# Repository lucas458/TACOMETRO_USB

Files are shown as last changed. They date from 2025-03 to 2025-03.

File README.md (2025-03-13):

# TACOMETRO USB
## Tacômetro USB para jogos usando PIC12F1822.

#### Placa
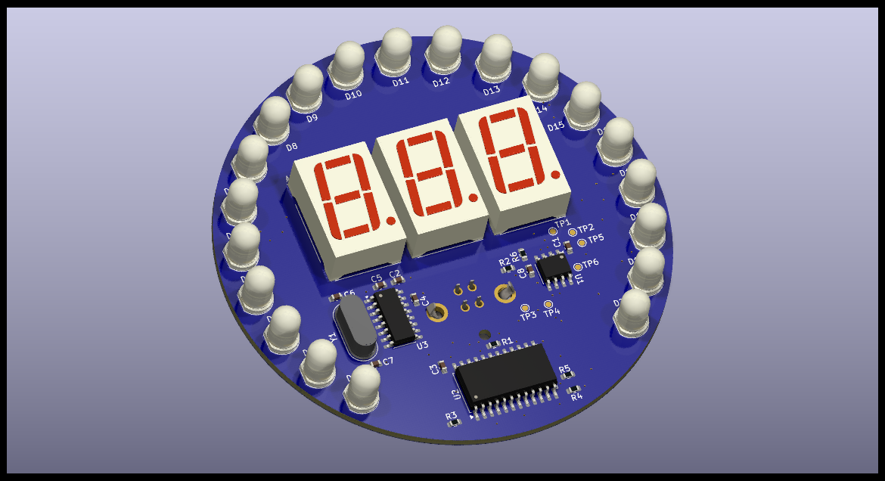
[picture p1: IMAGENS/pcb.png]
Placa da Placa Frente da placa


### Os dados a serem enviados são compostos por 6 bytes e serão transmitidos pela porta serial.
| Buffer Index | Valor (decimal) | Descrição |
| --- | --- | --- |
| 0 | 0 a 255 | Digito 0 |
| 1 | 0 a 255 | Digito 1 |
| 2 | 0 a 255 | Digito 2 |
| 3 | 0 a 20 | Quantidade de LEDS ligados |
| 4 | 0 a 15 | Brilho |
| 5 | '\r' ou '\n' | **Caractere obrigatório** |

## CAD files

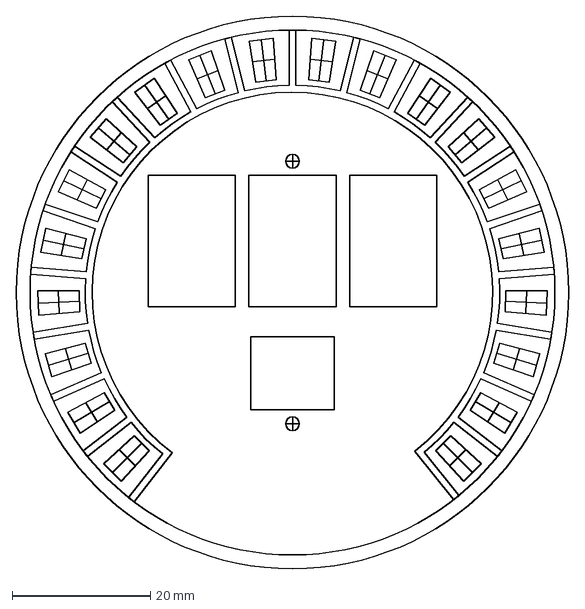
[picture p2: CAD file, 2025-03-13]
PCB/ledGaugePCB.dxf
80.0 x 80.0 mm

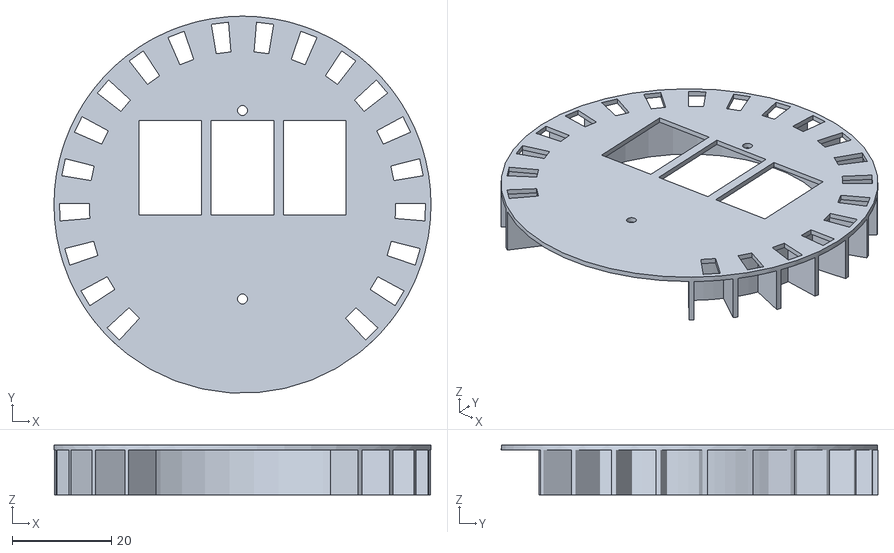
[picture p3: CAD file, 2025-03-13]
ESTRUTURA/frente.stl
76.0 x 75.9 x 10.0

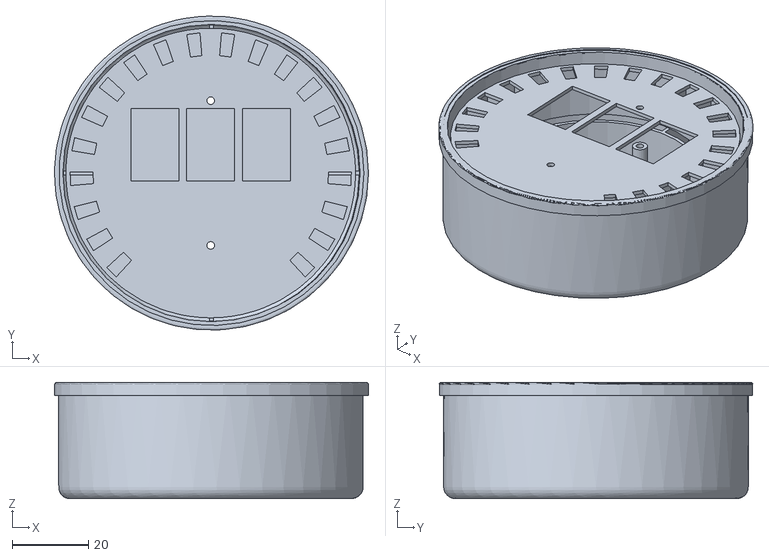
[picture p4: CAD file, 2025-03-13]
ESTRUTURA/estrutura.stl
82.4 x 82.3 x 30.5

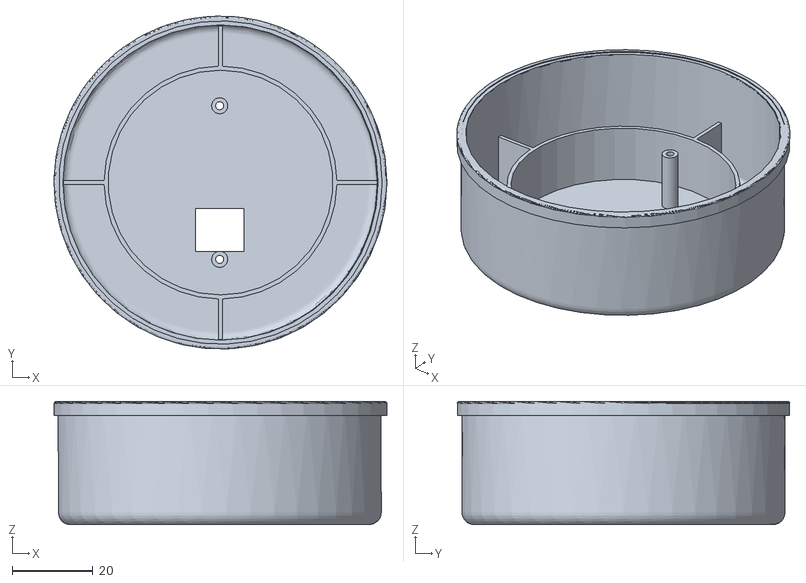
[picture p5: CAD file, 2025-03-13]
ESTRUTURA/corpo.stl
82.4 x 82.3 x 30.5

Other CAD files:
ESTRUTURA/estruturaProjeto.dwg
ESTRUTURA/estrutura.dwg

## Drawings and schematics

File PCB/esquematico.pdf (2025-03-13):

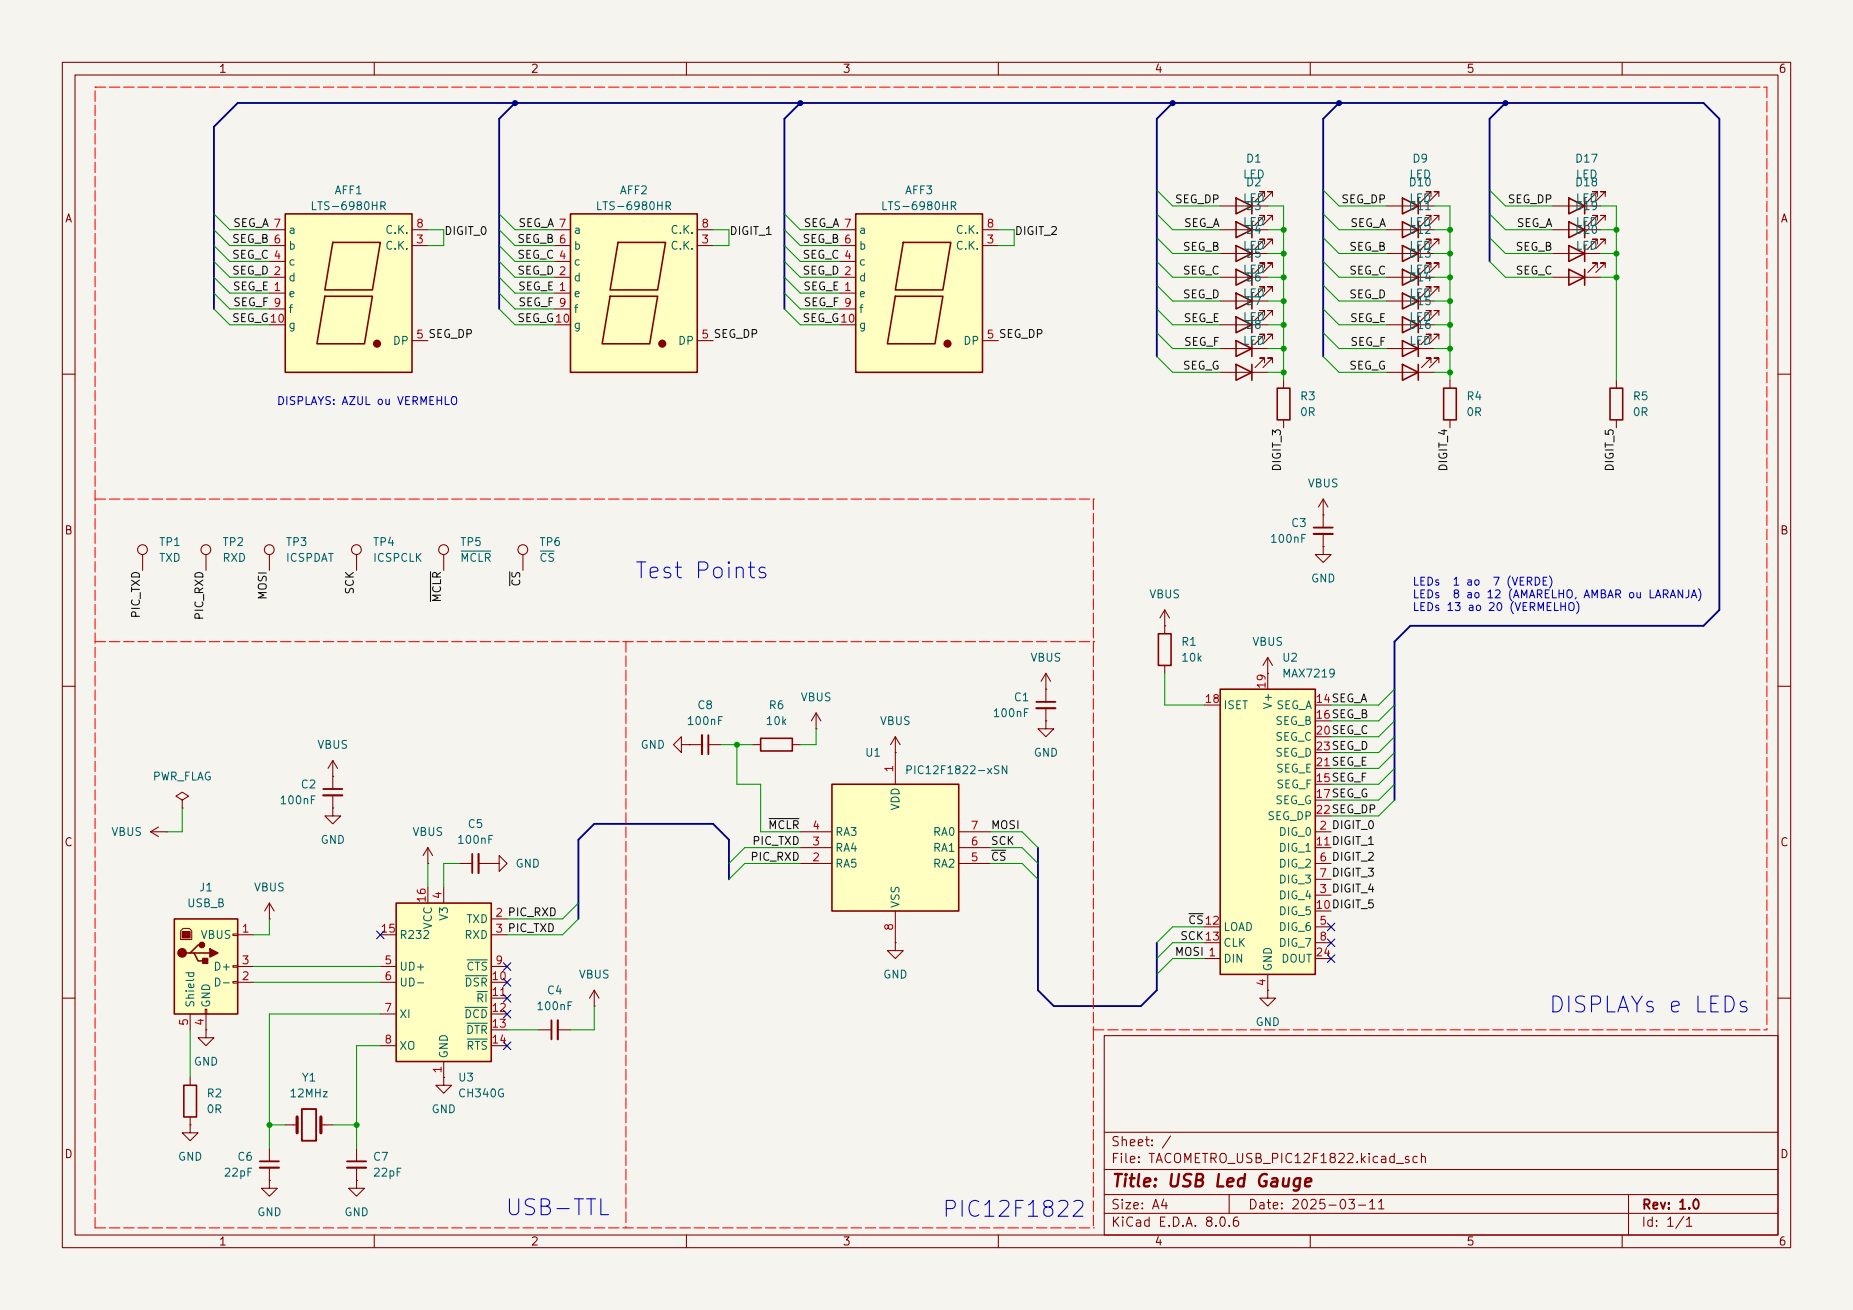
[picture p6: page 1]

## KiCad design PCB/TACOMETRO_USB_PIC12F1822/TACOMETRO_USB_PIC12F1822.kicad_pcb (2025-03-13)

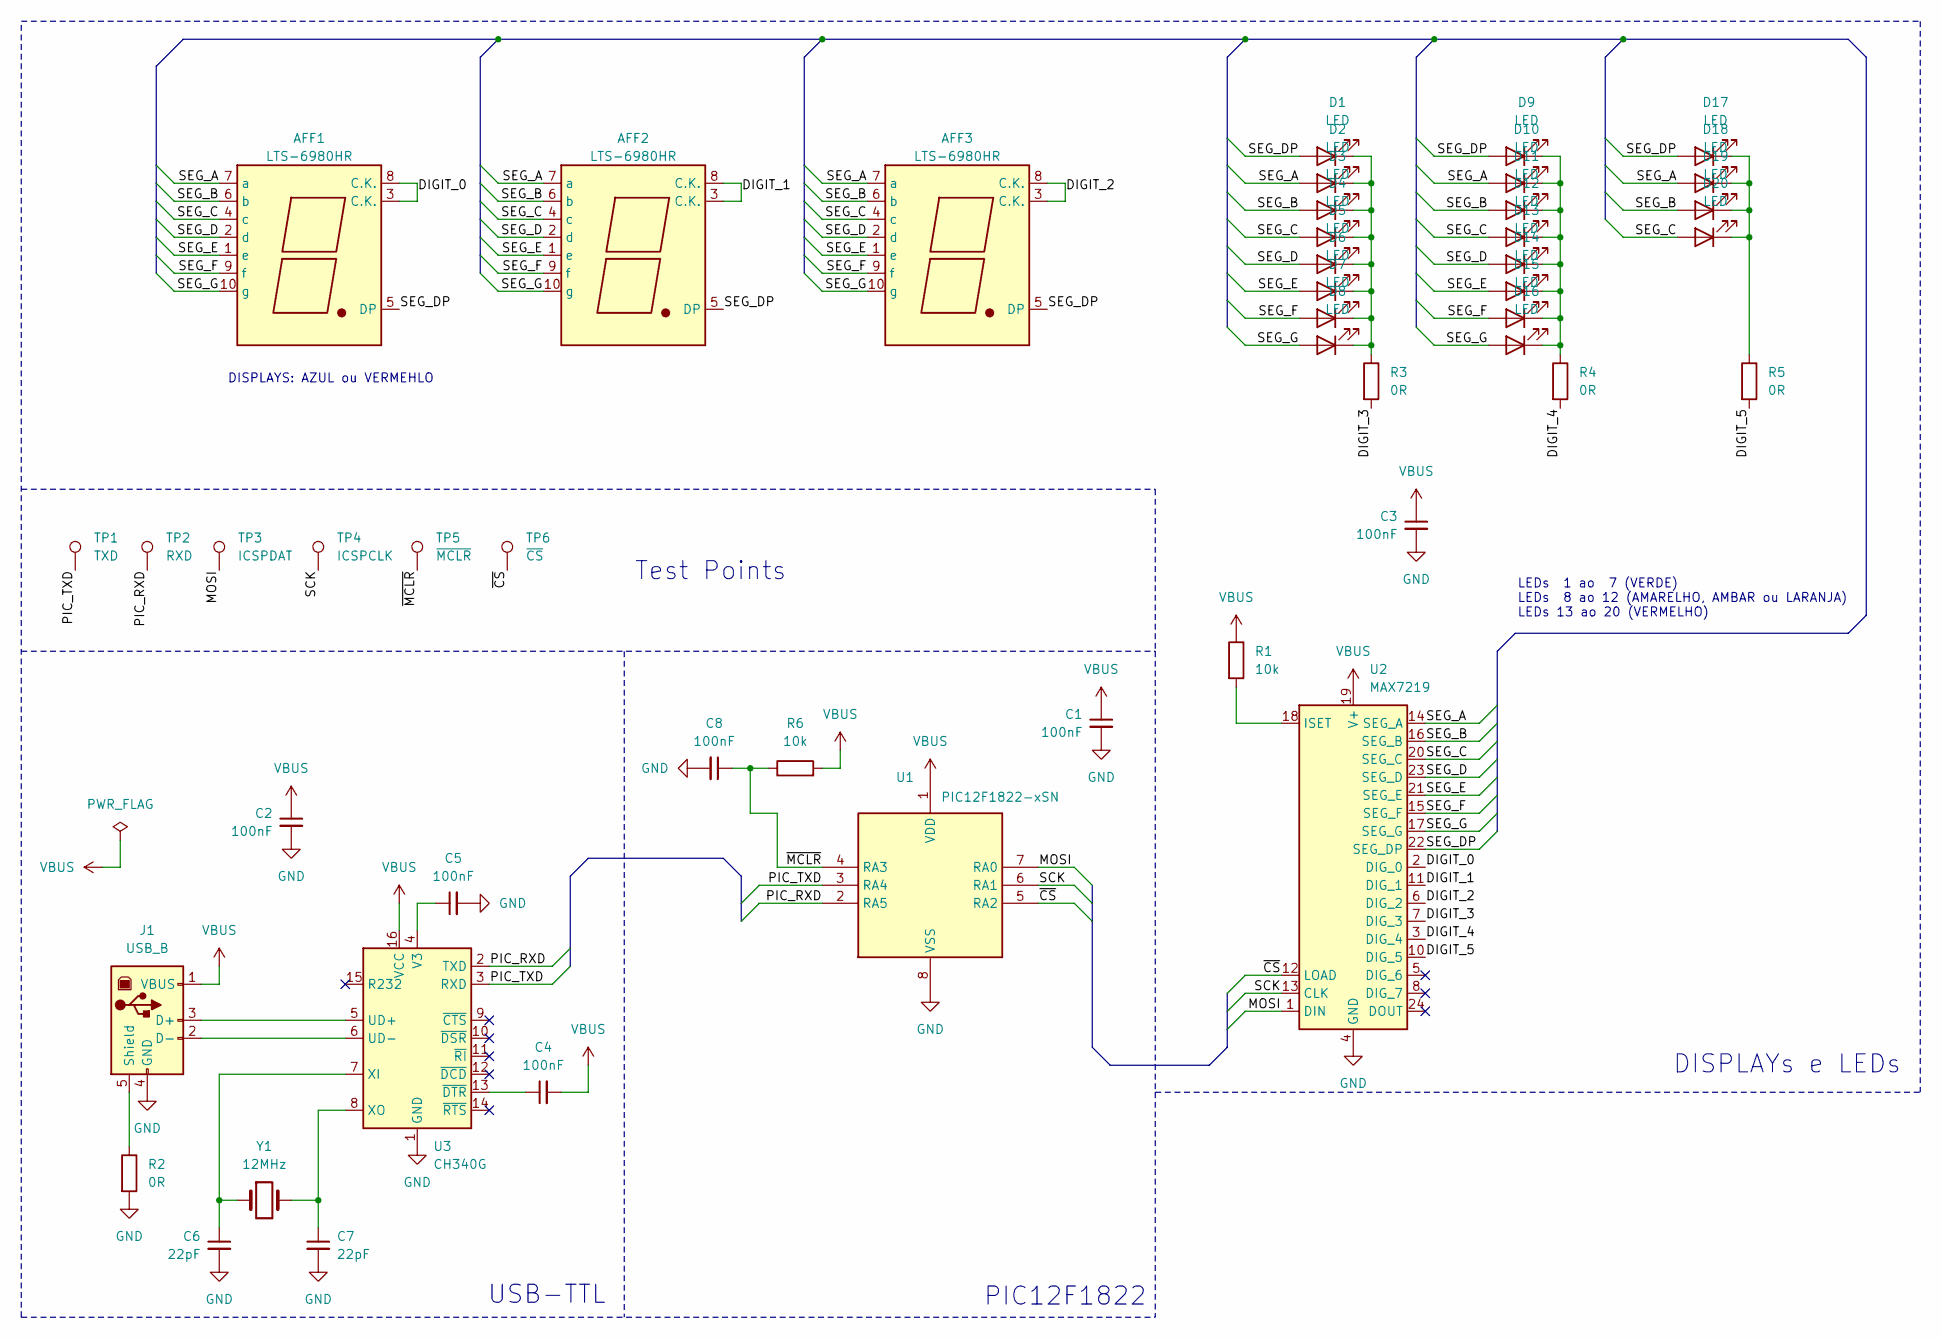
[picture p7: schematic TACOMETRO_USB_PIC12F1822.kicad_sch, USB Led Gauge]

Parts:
AFF1, AFF2, AFF3: LTS-6980HR; 7SegmentLED_LTS6760_LTS6780
C1, C2, C3, C4, C5, C8: 100nF; C_0603_1608Metric
C6, C7: 22pF; C_0603_1608Metric
D1, D2, D3, D4, D5, D6, D7, D8, D9, D10, D11, D12, D13, D14, D15, D16, D17, D18, D19, D20: LED; LED_D5.0mm_Clear
J1: USB_B; 5787834-1
R1, R6: 10k; R_0603_1608Metric
R2, R3, R4, R5: 0R; R_0603_1608Metric
TP1: TXD; TestPoint_Pad_D1.0mm
TP2: RXD; TestPoint_Pad_D1.0mm
TP3: ICSPDAT; TestPoint_Pad_D1.0mm
TP4: ICSPCLK; TestPoint_Pad_D1.0mm
TP5: ~{MCLR}; TestPoint_Pad_D1.0mm
TP6: ~{CS}; TestPoint_Pad_D1.0mm
U1: PIC12F1822-xSN; SOIC-8_3.9x4.9mm_P1.27mm
U2: MAX7219; SOIC-24W_7.5x15.4mm_P1.27mm
U3: CH340G; SOIC-16_3.9x9.9mm_P1.27mm
Y1: 12MHz; Crystal_HC49-U_Vertical

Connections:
/DIGIT_0: AFF1.3 (C.K.), AFF1.8 (C.K.), U2.2 (DIG_0)
/DIGIT_1: AFF2.3 (C.K.), AFF2.8 (C.K.), U2.11 (DIG_1)
/DIGIT_2: AFF3.3 (C.K.), AFF3.8 (C.K.), U2.6 (DIG_2)
/DIGIT_3: R3.2, U2.7 (DIG_3)
/DIGIT_4: R4.2, U2.3 (DIG_4)
/DIGIT_5: R5.2, U2.10 (DIG_5)
/MOSI: TP3.1, U1.7 (RA0), U2.1 (DIN)
/PIC_RXD: TP2.1, U1.2 (RA5), U3.2 (TXD)
/PIC_TXD: TP1.1, U1.3 (RA4), U3.3 (RXD)
/SCK: TP4.1, U1.6 (RA1), U2.13 (CLK)
/SEG_A: AFF1.7 (a), AFF2.7 (a), AFF3.7 (a), D2.2 (A), D10.2 (A), D18.2 (A), U2.14 (SEG_A)
/SEG_B: AFF1.6 (b), AFF2.6 (b), AFF3.6 (b), D3.2 (A), D11.2 (A), D19.2 (A), U2.16 (SEG_B)
/SEG_C: AFF1.4 (c), AFF2.4 (c), AFF3.4 (c), D4.2 (A), D12.2 (A), D20.2 (A), U2.20 (SEG_C)
/SEG_D: AFF1.2 (d), AFF2.2 (d), AFF3.2 (d), D5.2 (A), D13.2 (A), U2.23 (SEG_D)
/SEG_DP: AFF1.5 (DP), AFF2.5 (DP), AFF3.5 (DP), D1.2 (A), D9.2 (A), D17.2 (A), U2.22 (SEG_DP)
/SEG_E: AFF1.1 (e), AFF2.1 (e), AFF3.1 (e), D6.2 (A), D14.2 (A), U2.21 (SEG_E)
/SEG_F: AFF1.9 (f), AFF2.9 (f), AFF3.9 (f), D7.2 (A), D15.2 (A), U2.15 (SEG_F)
/SEG_G: AFF1.10 (g), AFF2.10 (g), AFF3.10 (g), D8.2 (A), D16.2 (A), U2.17 (SEG_G)
/~CS: TP6.1, U1.5 (RA2), U2.12 (LOAD)
/~MCLR: C8.1, R6.1, TP5.1, U1.4 (RA3)
GND: C1.2, C2.2, C3.2, C5.2, C6.2, C7.2, C8.2, J1.4 (GND), R2.2, U1.8 (VSS), U2.4 (GND), U2.9 (GND), U3.1 (GND)
unnamed: D1.1 (K), D2.1 (K), D3.1 (K), D4.1 (K), D5.1 (K), D6.1 (K), D7.1 (K), D8.1 (K), R3.1
unnamed: D9.1 (K), D10.1 (K), D11.1 (K), D12.1 (K), D13.1 (K), D14.1 (K), D15.1 (K), D16.1 (K), R4.1
unnamed: D17.1 (K), D18.1 (K), D19.1 (K), D20.1 (K), R5.1
unnamed: J1.3 (D+), U3.5 (UD+)
unnamed: J1.2 (D-), U3.6 (UD-)
unnamed: J1.5 (Shield), R2.1
unnamed: R1.2, U2.18 (ISET)
unnamed: C5.1, U3.4 (V3)
unnamed: C6.1, U3.7 (XI), Y1.1
unnamed: C7.1, U3.8 (XO), Y1.2
unnamed: C4.1, U3.13 (~DTR)
VBUS: C1.1, C2.1, C3.1, C4.2, J1.1 (VBUS), R1.1, R6.2, U1.1 (VDD), U2.19 (V+), U3.16 (VCC)

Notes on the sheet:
Test Points
USB-TTL
LEDs 1 ao 7 (VERDE) LEDs 8 ao 12 (AMARELHO, AMBAR ou LARANJA) LEDs 13 ao 20 (VERMELHO)
DISPLAYS: AZUL ou VERMEHLO
PIC12F1822
DISPLAYs e LEDs

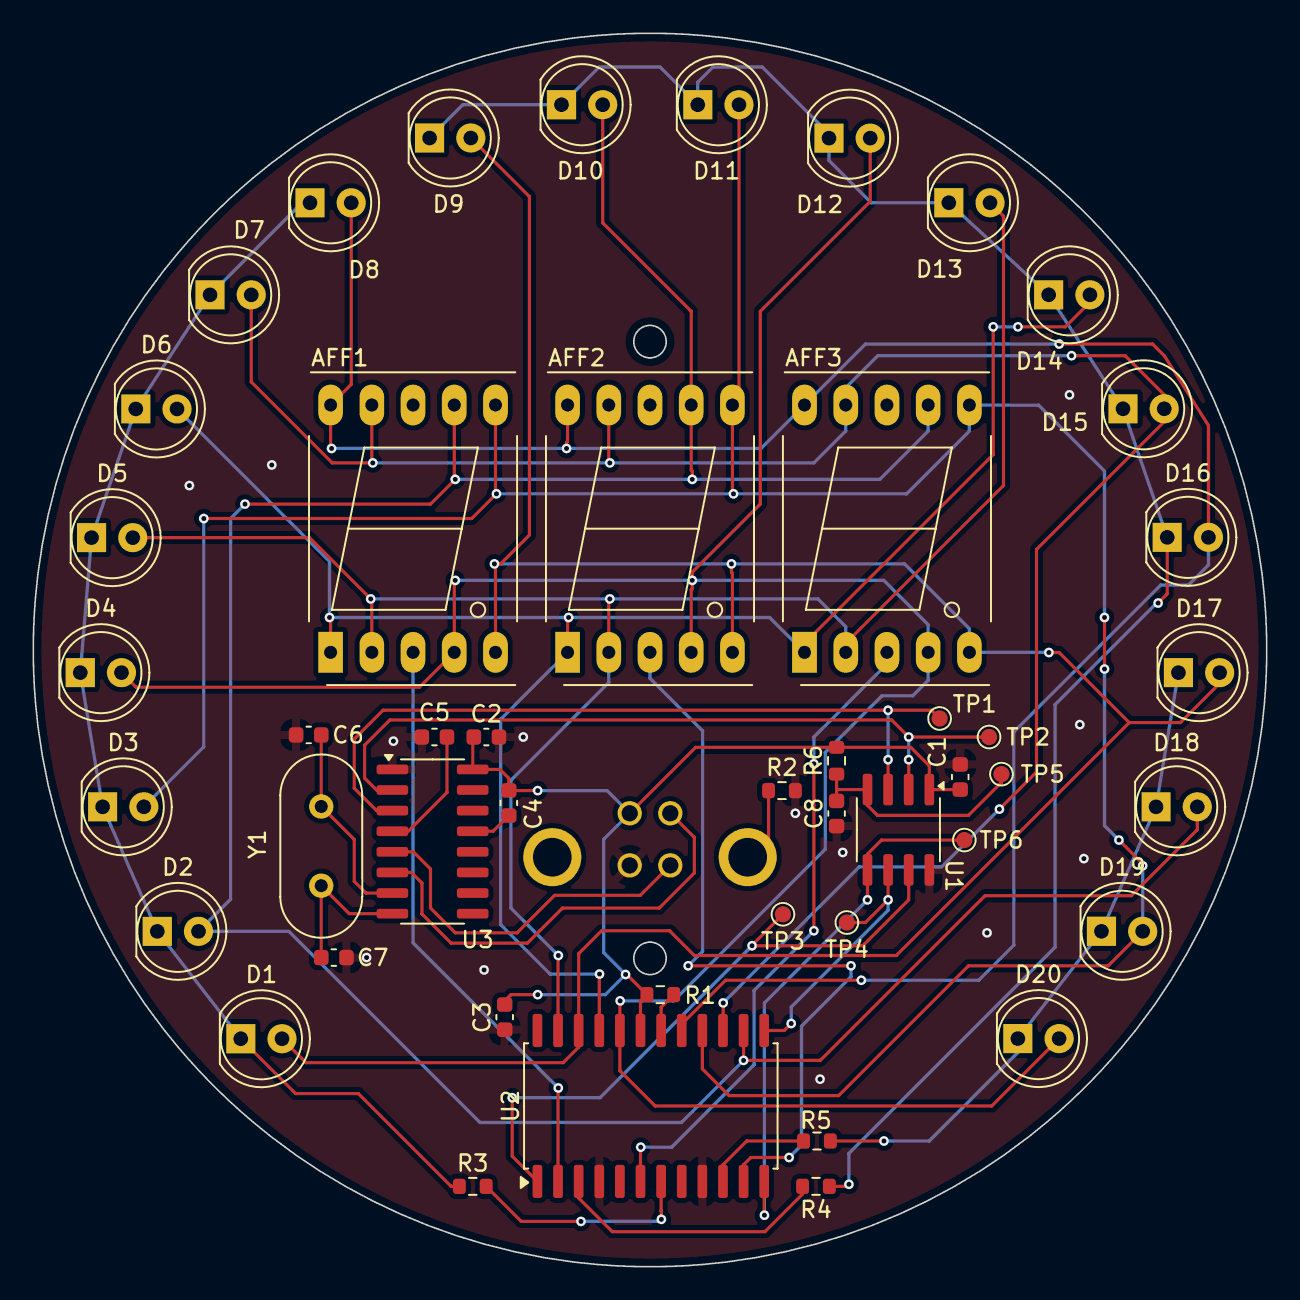
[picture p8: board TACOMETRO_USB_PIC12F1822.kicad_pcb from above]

Board: 2 copper layers, 76.0 x 76.0 mm, 48 parts (1 on the bottom side), 33 nets.

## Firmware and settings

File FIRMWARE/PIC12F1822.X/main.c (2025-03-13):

/*
 * File:   main.c
 * Author: Lucas
 *
 * Created on 17 de Janeiro de 2025, 16:14
 * 
 * XC8 (v2.46)
 */


// CONFIG1
#pragma config FOSC		= INTOSC  // Oscillator Selection (INTOSC oscillator: I/O function on CLKIN pin)
#pragma config WDTE		= OFF     // Watchdog Timer Enable (WDT disabled)
#pragma config PWRTE	= ON      // Power-up Timer Enable (PWRT enabled)
#pragma config MCLRE	= OFF     // MCLR Pin Function Select (MCLR/VPP pin function is digital input)
#pragma config CP		= OFF     // Flash Program Memory Code Protection (Program memory code protection is disabled)
#pragma config CPD		= OFF     // Data Memory Code Protection (Data memory code protection is disabled)
#pragma config BOREN	= ON      // Brown-out Reset Enable (Brown-out Reset enabled)
#pragma config CLKOUTEN = OFF	  // Clock Out Enable (CLKOUT function is disabled. I/O or oscillator function on the CLKOUT pin)
#pragma config IESO		= ON      // Internal/External Switchover (Internal/External Switchover mode is enabled)
#pragma config FCMEN	= ON      // Fail-Safe Clock Monitor Enable (Fail-Safe Clock Monitor is enabled)

// CONFIG2
#pragma config WRT		= OFF     // Flash Memory Self-Write Protection (Write protection off)
#pragma config PLLEN	= ON      // PLL Enable (4x PLL enabled)
#pragma config STVREN	= ON      // Stack Overflow/Underflow Reset Enable (Stack Overflow or Underflow will cause a Reset)
#pragma config BORV		= LO      // Brown-out Reset Voltage Selection (Brown-out Reset Voltage (Vbor), low trip point selected.)
#pragma config LVP		= ON      // Low-Voltage Programming Enable (Low-voltage programming enabled)

// #pragma config statements should precede project file includes.
// Use project enums instead of #define for ON and OFF.

#define _XTAL_FREQ	32000000
#include <xc.h>



volatile struct Buffer_s{
	uint8_t data[6];
	uint8_t index;
} Buffer;

/*
 data[0] = Display 0 Data
 data[1] = Display 1 Data
 data[2] = Display 2 Data
 data[3] = Amount of LEDs (0 to 20)
 data[4] = Brightness (0 to 15)
 data[5] = '\r' or '\n'
 */



const uint8_t initSequence[][2] = {
	{0xC, 0x1}, // Shutdown Register Format:		Normal Operation
	{0x9, 0x0}, // Decode-Mode Register Examples:	No decode for digits 7–0
	{0xA, 0xF}, // Intensity Register Format:		31/32 (max on)
	{0xB, 0x5}, // Scan-Limit Register Format:		Display digits 0-5
	{0xF, 0x0}, // Display-Test Register Format:	Normal Operation
	// Self-Test (ALL SEGMENTS ON)
	{1, 0xFF},{2, 0xFF},{3, 0xFF},{4, 0xFF},{5, 0xFF},{6, 0xFF},{7, 0xFF},{8, 0xFF}
};






/****** MAX7219 -- Driver ******/
#define MAX7219_CS	LATAbits.LATA2


void max7219_write(uint8_t address, uint8_t data){
	MAX7219_CS = 0;
		SSPBUF = address;while (SSPSTATbits.BF) NOP();
		SSPBUF = data;while (SSPSTATbits.BF) NOP();
	MAX7219_CS = 1;
}








void main(){
	OSCCONbits.IRCF = 0b1110;
	while ( !OSCSTATbits.HFIOFR );
	
	ANSELA = 0x00; // Digital I/O. Pin is assigned to port or digital special function.
	APFCON = 0x84; // Rx(RA4) | Tx(RA5)
	
	MAX7219_CS = 1;
	TRISA = 0xF8;
	
	
	// USART Async: BRGH=1; BRG16=1 | 115900 (115200) Error 0.64% at Fosc=32MHz
	TXSTA	= 0x24;
	RCSTA	= 0x90;
	BAUDCON = 0x48;
	SPBRGH	= 0;
	SPBRGL	= 68;
	
	
	// SPI Master: Fosc / 4 | SPI Mode: 0
	SSPSTAT  = 0x00;
	SSP1CON1 = 0x20;
	
	
	// MAX7219 INIT SEQUENCE
	for (uint8_t i = 0; i < sizeof(initSequence)/2; i++){
		max7219_write(initSequence[i][0], initSequence[i][1]);
	}
	
	__delay_ms(1000);
	
	// End: Selt-Test (ALL SEGMENTS OFF)
	for (uint8_t i = 1; i <= 8; i++){
		max7219_write(i, 0x00);
	}
	
	
	
	// INTERRUPTS
	INTCONbits.PEIE = 1;
	PIR1bits.RCIF   = 0;
	PIE1bits.RCIE   = 1;
	ei();
	
	
	while (1){
		
		if ( Buffer.index >= 6 ){
			Buffer.index = 0;
			
			if ( Buffer.data[5] == '\r' || Buffer.data[5] == '\n' ){
				di();
				
				// --- Set Displays ---
				max7219_write(1, Buffer.data[0]); // Digit 0
				max7219_write(2, Buffer.data[1]); // Digit 1
				max7219_write(3, Buffer.data[2]); // Digit 2
				
				
				// --- Set LEDs ---
				uint8_t currentLedIndex = 0;
				
				if (Buffer.data[3] > 20 ){
					Buffer.data[3] = 20;
				}
				
				for (uint8_t i = 0; i < 3; i++){ // 3x LEDs Groups 8+8+4 = 20
					uint8_t tempData = 0x00;

					for (uint8_t j = 0; j < 8; j++, currentLedIndex++){

						if ( currentLedIndex < Buffer.data[3] ){
							tempData |= 1 << (7 - j);
						}
					}
					
					max7219_write(4+i, tempData);
					
				}
				
				
				// --- Set Brightness ---
				max7219_write(0x0A, Buffer.data[4] & 0xF);
				
				ei();
			}
			
		}
		
	}
	
}




void __interrupt() ISR(){
	
	if ( RCIE && RCIF ){
		uint8_t data = RCREG;
		
		if ( Buffer.index < sizeof(Buffer.data) ){
			Buffer.data[Buffer.index] = data;
			Buffer.index++;
		}
		
	}
	
}
